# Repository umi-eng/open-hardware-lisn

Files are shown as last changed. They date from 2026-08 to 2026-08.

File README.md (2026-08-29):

# Open Hardware Dual DC LISN

This is a line impedance stabilization network for measuring conducted emissions to aid in evaluating designs for EMC compliance. It's based on an existing design from Rhode & Schwarz, which only existed as Gerber outputs.

This design is intended as a development tool and not suitable for empirical compliance testing.

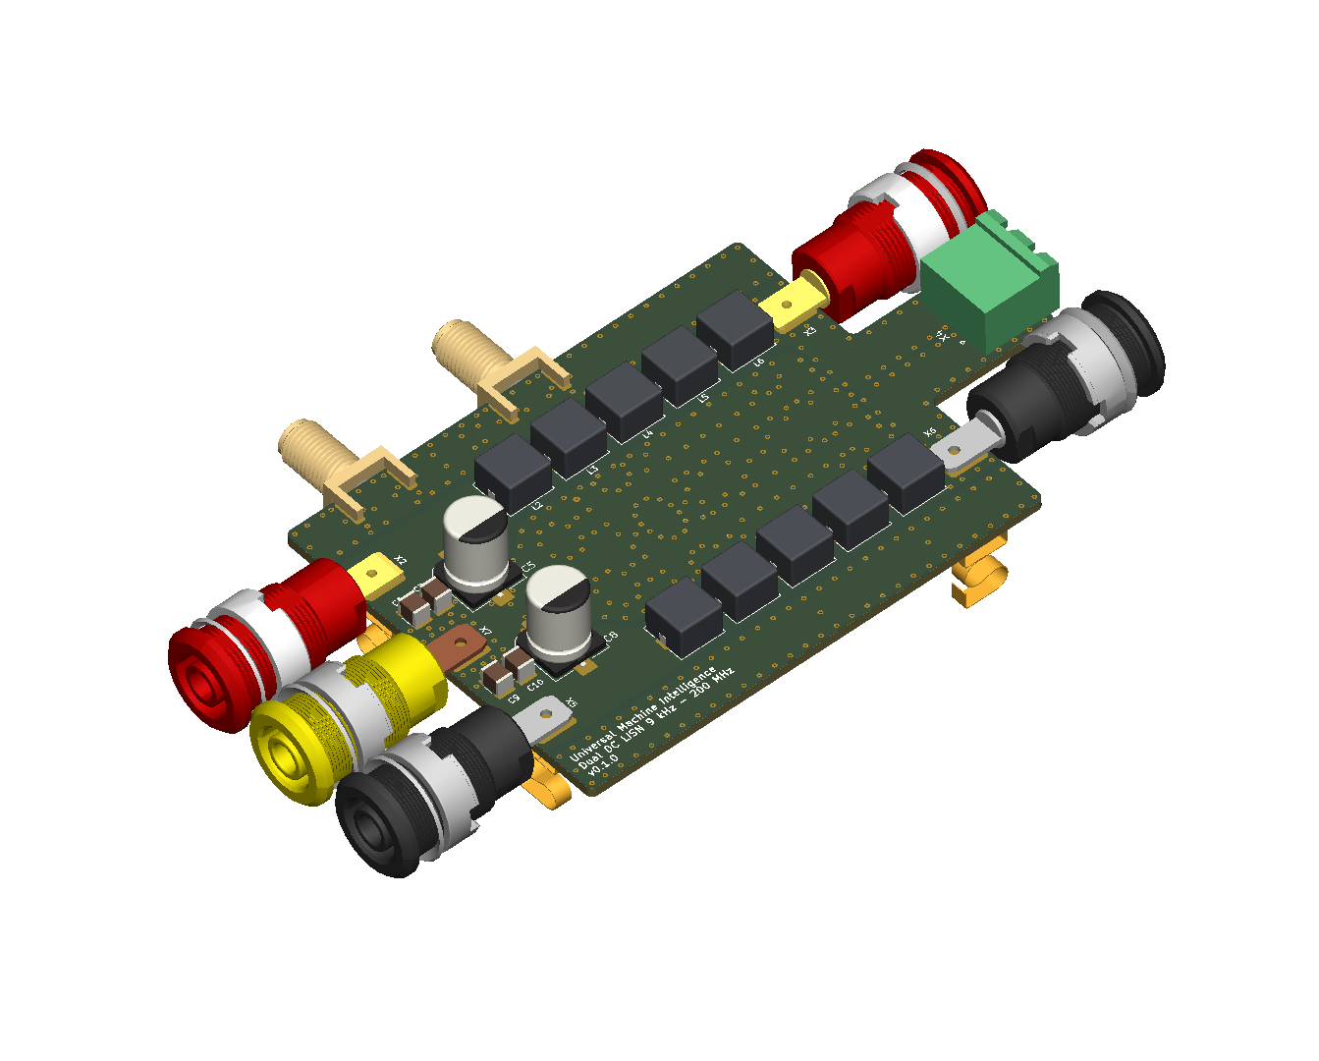
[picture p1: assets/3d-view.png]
3D board render


## References

- [A homemade LISN for precompliance conducted emission tests on DC-DC power supplies - Rhode & Schwarz](https://www.rohde-schwarz.com/au/applications/a-homemade-lisn-for-precompliance-conducted-emission-tests-on-dc-dc-power-supplies_56279-1010752.html)

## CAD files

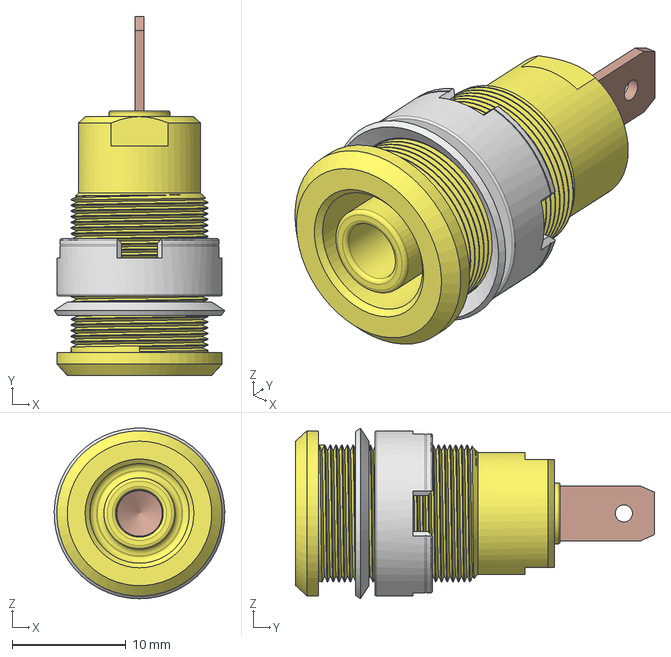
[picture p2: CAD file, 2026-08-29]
Models/23.3000-24.stp
15.0 x 31.5 x 15.0 mm

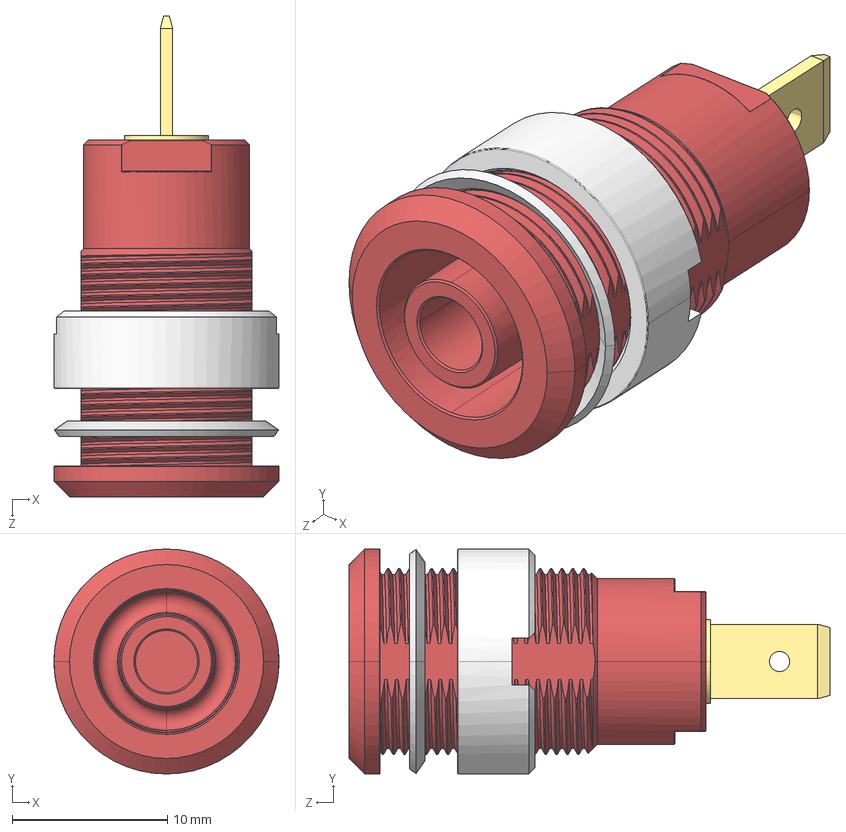
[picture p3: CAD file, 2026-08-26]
Models/23.3000-22.stp
14.5 x 14.5 x 31.0 mm

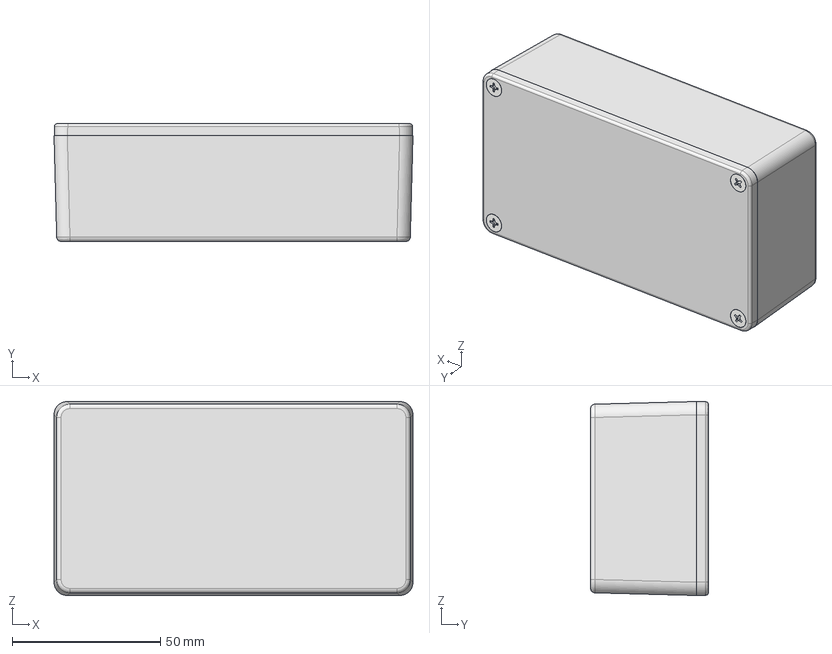
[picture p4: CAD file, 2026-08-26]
Models/1590N1.stp
121.2 x 39.8 x 65.5 mm

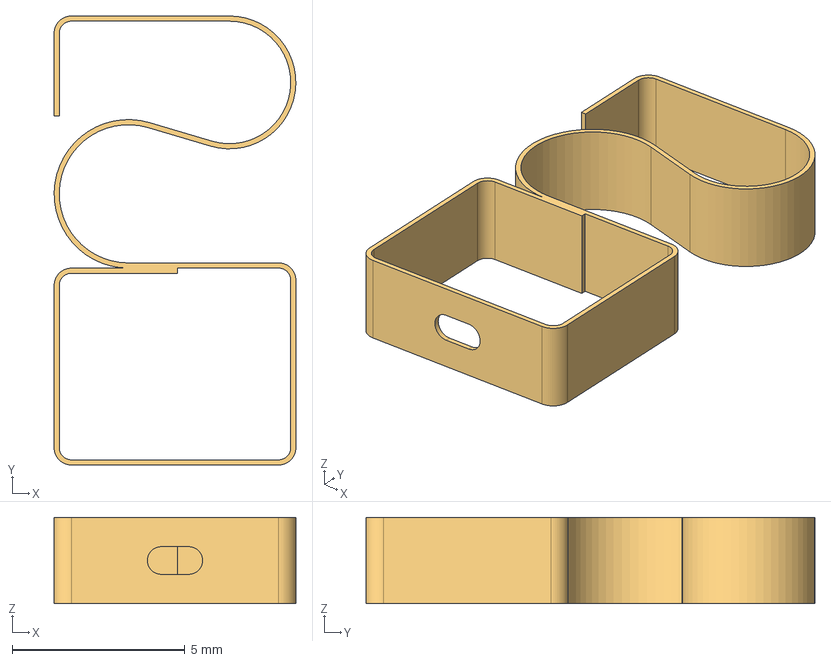
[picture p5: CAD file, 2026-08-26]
Models/331161702513 (rev1).stp
7.00 x 13.0 x 2.50 mm

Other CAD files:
Models/23.3000-21.stp

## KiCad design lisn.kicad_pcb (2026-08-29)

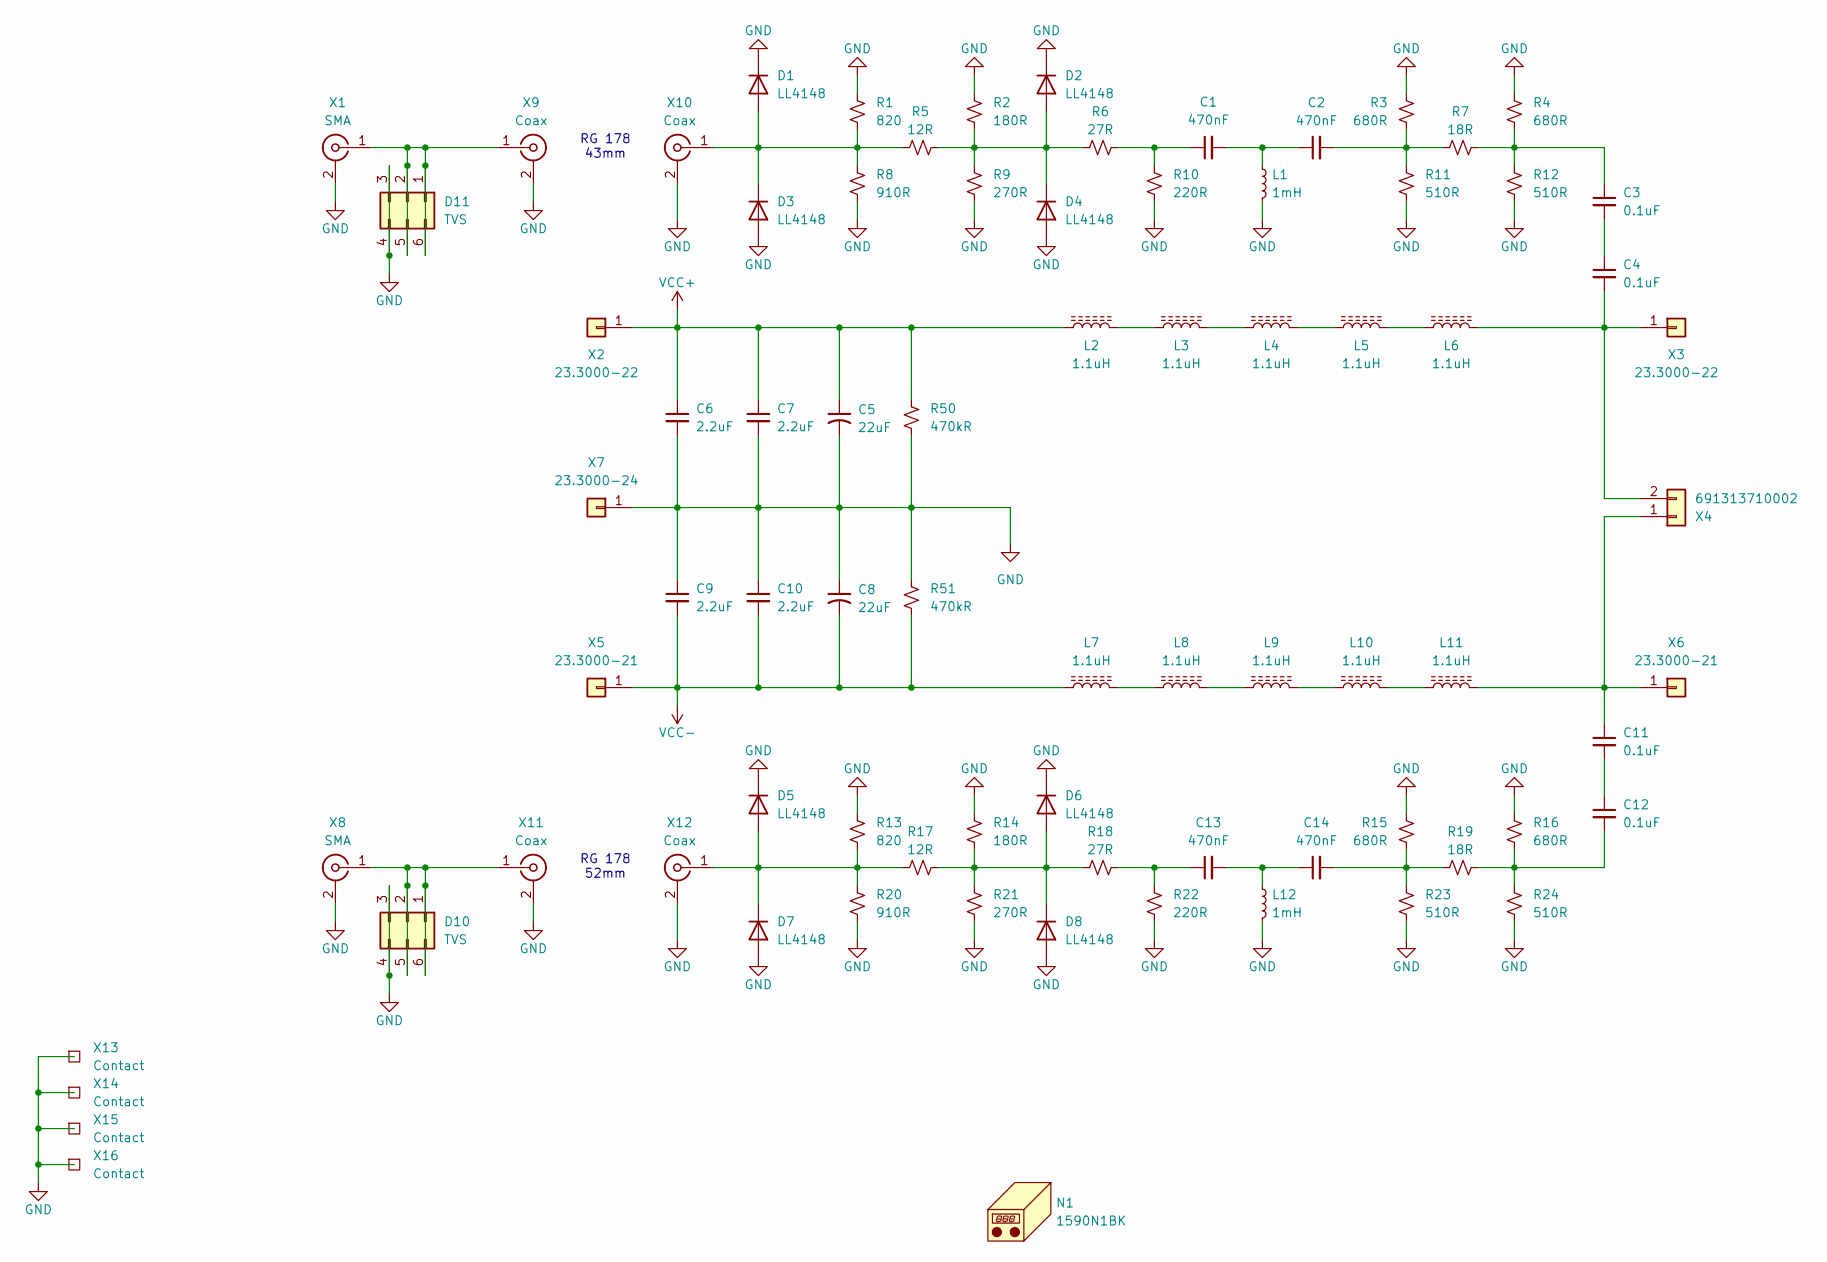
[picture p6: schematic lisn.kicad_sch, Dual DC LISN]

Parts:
C1, C2, C13, C14: 470nF; C_0805_2012Metric; Voltage 50V; Mouser 710-885012207102
C3, C4, C11, C12: 0.1uF; C_1206_3216Metric; Voltage 250V; Mouser 710-885342208004
C5, C8: 22uF; CP_Elec_8x10.5; Voltage 100V; Mouser 710-865060853003
C6, C7, C9, C10: 2.2uF; C_1210_3225Metric; Voltage 100V; Mouser 710-885012209071
D1, D2, D3, D4, D5, D6, D7, D8: LL4148; D_MiniMELF; Mouser 78-LL4148-M-08
D10, D11: TVS; DFN-6_1.3x1.2mm_P0.4mm; Mouser 710-824012823
L1, L12: 1mH; L_Wuerth_HCI-5040; Mouser 710-74404054102
L2, L3, L4, L5, L6, L7, L8, L9, L10, L11: 1.1uH; L_Wuerth_HCI-7050; Mouser 710-744314110
N1: 1590N1BK; Mouser 546-1590N1-BK
R1, R13: 820; R_0603_1608Metric; Mouser 667-ERJ-3EKF8200V
R2, R14: 180R; R_0603_1608Metric; Mouser 667-ERJ-3EKF1800V
R3, R4, R15, R16: 680R; R_0603_1608Metric; Mouser 667-ERJ-3EKF6800V
R5, R17: 12R; R_0603_1608Metric; Mouser 667-ERJ-3EKF12R0V
R6, R18: 27R; R_0603_1608Metric; Mouser 667-ERJ-3EKF27R0V
R7, R19: 18R; R_0603_1608Metric; Mouser 667-ERJ-3EKF18R0V
R8, R20: 910R; R_0603_1608Metric; Mouser 667-ERJ-3EKF9100V
R9, R21: 270R; R_0603_1608Metric; Mouser 667-ERJ-3EKF2700V
R10, R22: 220R; R_0603_1608Metric; Mouser 667-ERJ-3EKF2200V
R11, R12, R23, R24: 510R; R_0603_1608Metric; Mouser 667-ERJ-3EKF5100V
R50, R51: 470kR; R_0603_1608Metric; Mouser 667-ERJ-3EKF4703V
X1, X8: SMA; SMA_Amphenol_132289_EdgeMount; Mouser 710-60312242114510
X2, X3: 23.3000-22; STAUBLI_23.3000-22_Red
X4: 691313710002; PhoenixContact_MSTBA_2,5_2-G-5,08_1x02_P5.08mm_Horizontal; Mouser 710-691313710002
X5, X6: 23.3000-21; STAUBLI_23.3000-21_Black
X7: 23.3000-24; STAUBLI_23.3000-24_Yellow
X9, X10, X11, X12: Coax; Jumper_RG178
X13, X14, X15, X16: Contact; Wurth_331161702513; Mouser 710-331161702513

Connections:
GND: C5.2, C6.2, C7.2, C8.1, C9.1, C10.1, D1.1 (K), D2.1 (K), D3.2 (A), D4.2 (A), D5.1 (K), D6.1 (K), D7.2 (A), D8.2 (A), D10.3, D10.4, D11.3, D11.4, L1.2, L12.2, R1.1, R2.1, R3.1, R4.1, R8.2, R9.2, R10.2, R11.2, R12.2, R13.1, R14.1, R15.1, R16.1, R20.2, R21.2, R22.2, R23.2, R24.2, R50.2, R51.1, X1.2 (Ext), X7.1 (Pin_1_1), X8.2 (Ext), X9.2 (Ext), X10.2 (Ext), X11.2 (Ext), X12.2 (Ext), X13.1 (1_1), X14.1 (1_1), X15.1 (1_1), X16.1 (1_1)
unnamed: C1.1, R6.2, R10.1
unnamed: C1.2, C2.1, L1.1
unnamed: C2.2, R3.2, R7.1, R11.1
unnamed: C3.1, R4.2, R7.2, R12.1
unnamed: C3.2, C4.1
unnamed: C11.2, C12.1
unnamed: C12.2, R16.2, R19.2, R24.1
unnamed: C13.1, R18.2, R22.1
unnamed: C13.2, C14.1, L12.1
unnamed: C14.2, R15.2, R19.1, R23.1
unnamed: D1.2 (A), D3.1 (K), R1.2, R5.1, R8.1, X10.1 (In)
unnamed: D2.2 (A), D4.1 (K), R2.2, R5.2, R6.1, R9.1
unnamed: D5.2 (A), D7.1 (K), R13.2, R17.1, R20.1, X12.1 (In)
unnamed: D6.2 (A), D8.1 (K), R14.2, R17.2, R18.1, R21.1
unnamed: D10.1, D10.2, D10.5, D10.6, X8.1 (In), X11.1 (In)
unnamed: D11.1, D11.2, D11.5, D11.6, X1.1 (In), X9.1 (In)
unnamed: L2.2, L3.1
unnamed: L3.2, L4.1
unnamed: L4.2, L5.1
unnamed: L5.2, L6.1
unnamed: L7.2, L8.1
unnamed: L8.2, L9.1
unnamed: L9.2, L10.1
unnamed: L10.2, L11.1
unnamed: C4.2, L6.2, X3.1 (Pin_1_1), X4.2
unnamed: C11.1, L11.2, X4.1, X6.1 (Pin_1_1)
VCC+: C5.1, C6.1, C7.1, L2.1, R50.1, X2.1 (Pin_1_1)
VCC-: C8.2, C9.2, C10.2, L7.1, R51.2, X5.1 (Pin_1_1)

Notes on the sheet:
RG 178 52mm
RG 178 43mm

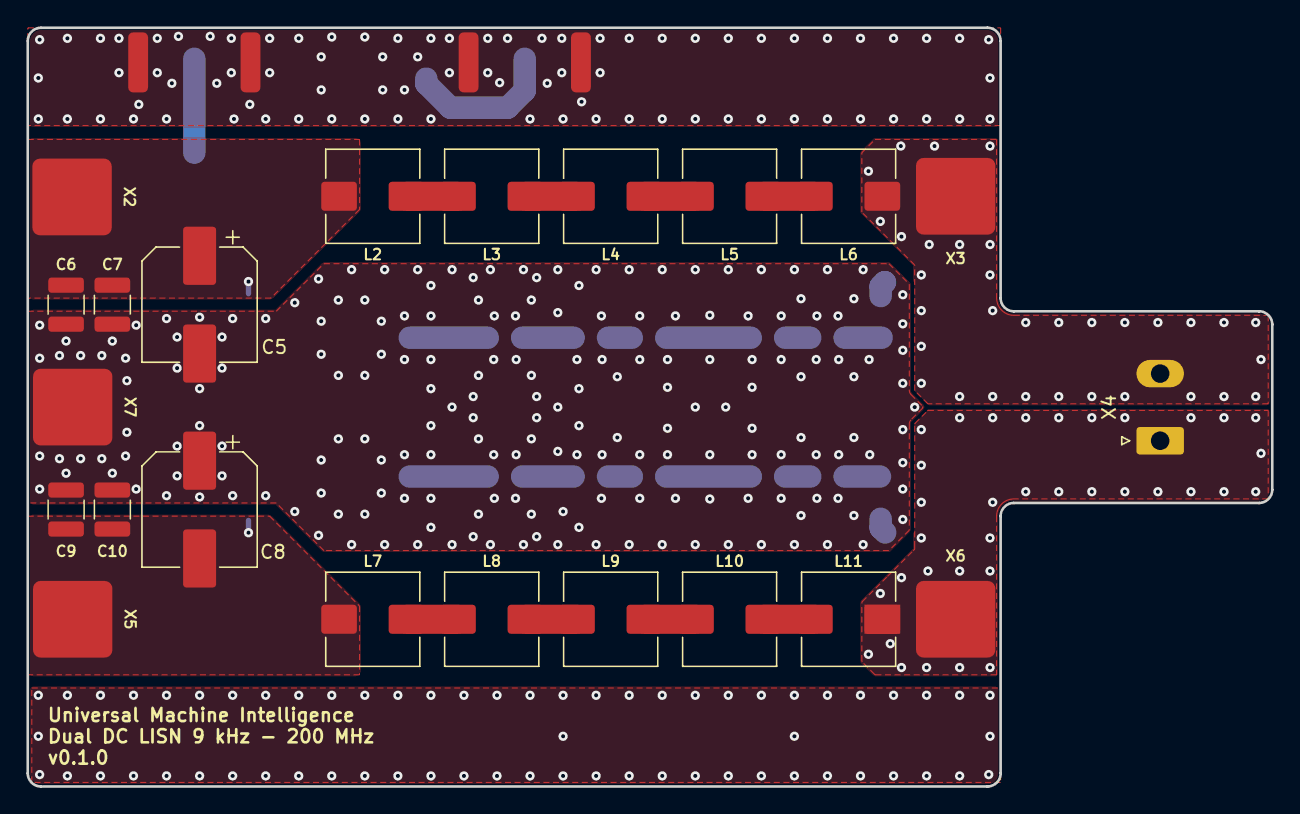
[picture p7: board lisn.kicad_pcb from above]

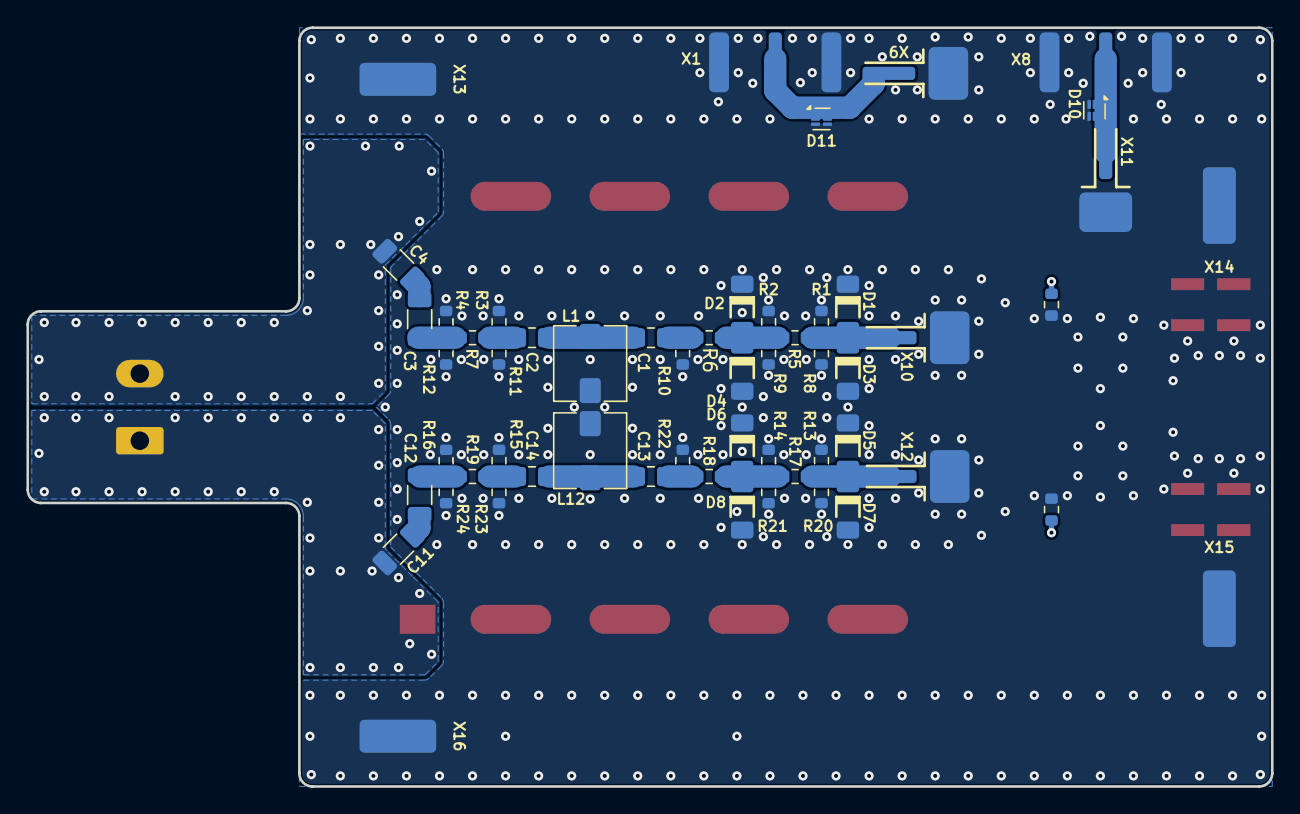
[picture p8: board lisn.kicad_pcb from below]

Board: 2 copper layers, 94.2 x 57.4 mm, 78 parts (56 on the bottom side), 29 nets.

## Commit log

2026-08-26 add initial progress
    [lisn.kicad_pcb, lisn.kicad_sch]
2026-08-26 add models
    [1590N1.stp, 23.3000-22.stp, 331161702513 (rev1).stp]
2026-08-29 add custom parts
    [23.3000-21.stp, 23.3000-24.stp]
2026-08-29 finalize cleanup
    [lisn.kicad_pcb, lisn.kicad_sch]
